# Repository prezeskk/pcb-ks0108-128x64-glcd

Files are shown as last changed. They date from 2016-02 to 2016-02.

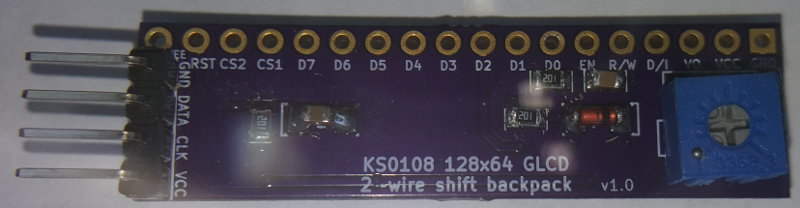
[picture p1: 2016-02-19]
doc/Soldered-Front.jpg

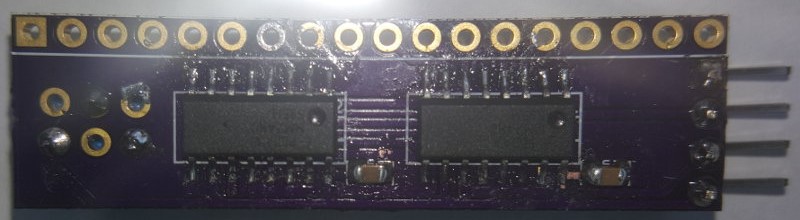
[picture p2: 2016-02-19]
doc/Soldered-Back.jpg

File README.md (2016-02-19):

# KS0108 128x64 Graphic LCD - 2-wire shift register backpack - v1.0 #

## Schematic ##



## Design Rules ##

* Clearance: 8 mil
* Track Width: 20 mil
* Via Diameter: 27 mil
* Via Drill: 13 mil
* Zone Clearance: 8 mil
* Zone Min Width: 8 mil
* Zone Thermal Antipad Clearance: 8 mil
* Zone Thermal Spoke Width: 15 mil

## PCB available on OSH Park ##

* 1.80" x 0.50" (45.82 mm x 12.80 mm)
* $1.50 each ($4.50 for 3)
* [https://oshpark.com/shared_projects/MtvXj55o](https://oshpark.com/shared_projects/MtvXj55o)

### PCB Front ###



### PCB Back ###



### Soldered Front ###



### Soldered Back ###



### Working Front ###



### Working Back ###



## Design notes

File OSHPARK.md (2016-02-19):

##KS0108 128x64 Graphic LCD - 2-wire shift register backpack - v1.0##

$1.50 each ($4.50 for 3)

NOTE: Working design, but AVR-GCC / Arduino library have not yet been published.

Component: [Sizes] **Values** (description)

* U1,U2: [SOIC-16N] **74HC595** (the shift registers)
* VR1: [3296W, 3362P (or similar)] **10k** (for contrast control)
* C1,C2: [0805] **0.1uF** (decoupling capacitors)
* C3: [1206] **1uF** (for reset delay)
* C4: [0805] **1nF** (for LCD enable line delay)
* D1: [SOD80 (~1206)] **LL4148** (for shift register latch)
* R1,R2,R3: [0805] **1k** (for shift register latch and LCD enable line delay)

[https://bitbucket.org/serisman/pcb-ks0108-128x64-glcd-backpack](https://bitbucket.org/serisman/pcb-ks0108-128x64-glcd-backpack)







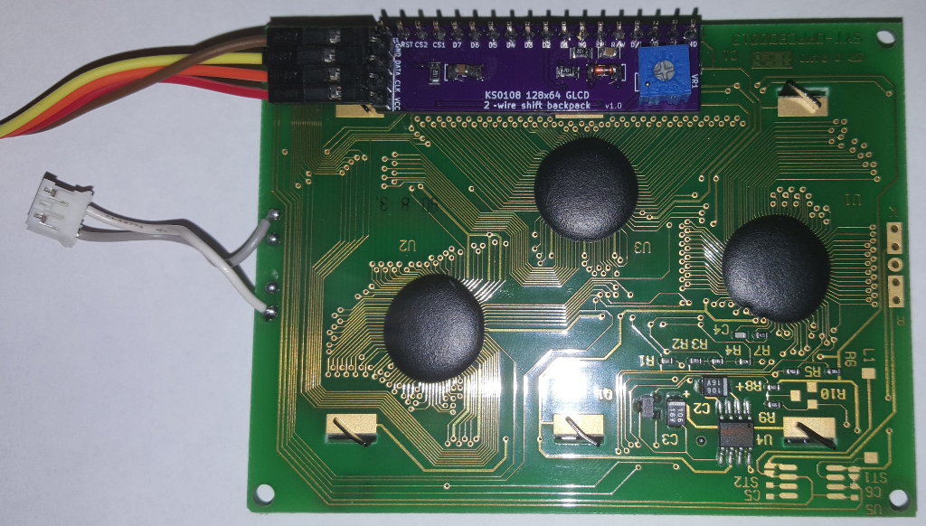
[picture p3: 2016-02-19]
doc/Working-Back.jpg

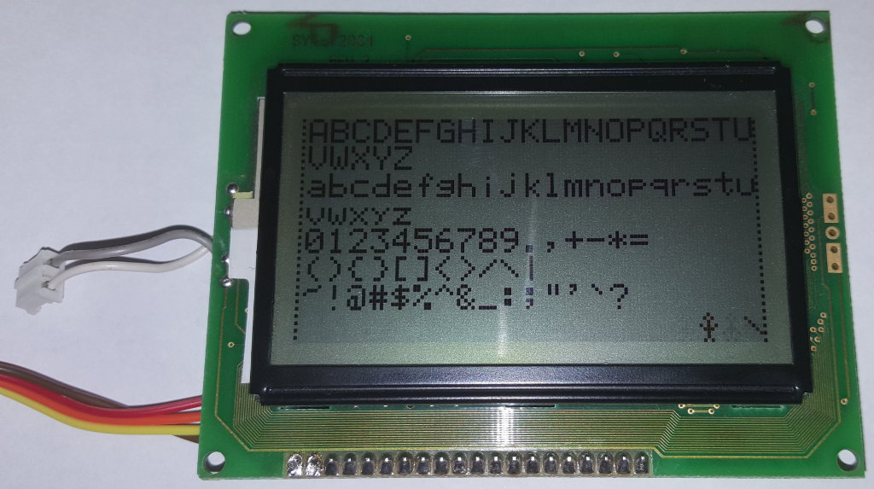
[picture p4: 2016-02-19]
doc/Working-Front.jpg

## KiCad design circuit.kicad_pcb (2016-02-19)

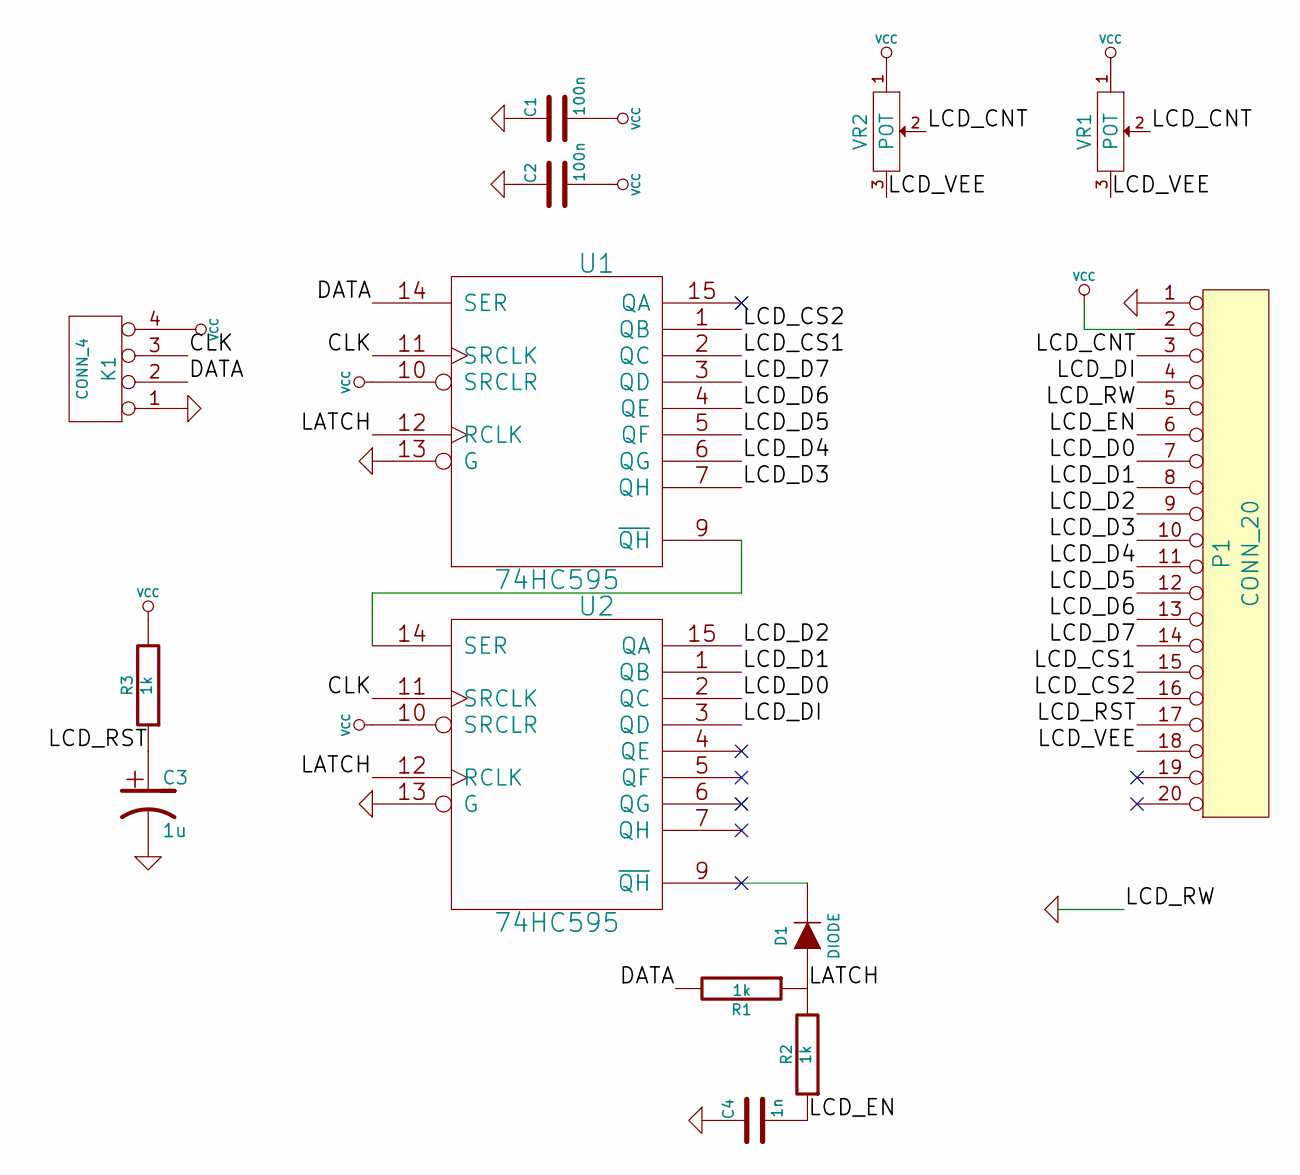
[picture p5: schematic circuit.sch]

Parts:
C1, C2: 100n
C3: 1u
C4: 1n
D1: DIODE
K1: CONN_4
P1: CONN_20
R1, R2, R3: 1k
U1, U2: 74HC595
VR1, VR2: POT

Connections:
/CLK: K1.3, U1.11 (SRCLK), U2.11 (SRCLK)
/DATA: K1.2, R1.2, U1.14 (SER)
/LATCH: D1.1 (A), R1.1, R2.2, U1.12 (RCLK), U2.12 (RCLK)
/LCD_CNT: P1.3, VR1.2, VR2.2
/LCD_CS1: P1.15, U1.2 (QC)
/LCD_CS2: P1.16, U1.1 (QB)
/LCD_D0: P1.7, U2.2 (QC)
/LCD_D1: P1.8, U2.1 (QB)
/LCD_D2: P1.9, U2.15 (QA)
/LCD_D3: P1.10, U1.7 (QH)
/LCD_D4: P1.11, U1.6 (QG)
/LCD_D5: P1.12, U1.5 (QF)
/LCD_D6: P1.13, U1.4 (QE)
/LCD_D7: P1.14, U1.3 (QD)
/LCD_DI: P1.4, U2.3 (QD)
/LCD_EN: C4.2, P1.6, R2.1
/LCD_RST: C3.1, P1.17, R3.1
/LCD_VEE: P1.18, VR1.3, VR2.3
GND: C1.1, C2.1, C3.2, C4.1, K1.1, P1.1, P1.5, U1.8 (GND), U1.13 (G), U2.8 (GND), U2.13 (G)
unnamed: U1.9 (~QH), U2.14 (SER)
unnamed: D1.2 (K), U2.9 (~QH)
VCC: C1.2, C2.2, K1.4, P1.2, R3.2, U1.10 (SRCLR), U1.16 (VCC), U2.10 (SRCLR), U2.16 (VCC), VR1.1, VR2.1

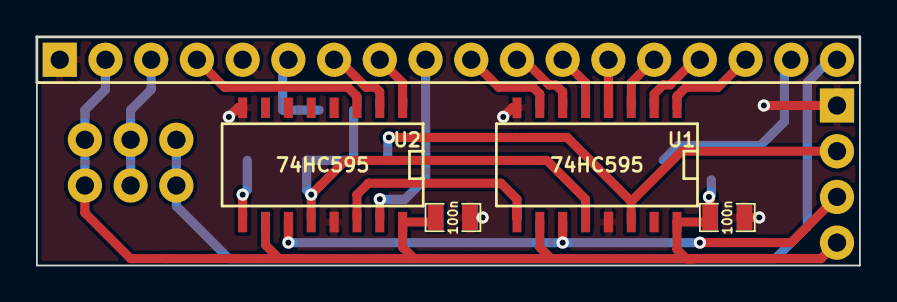
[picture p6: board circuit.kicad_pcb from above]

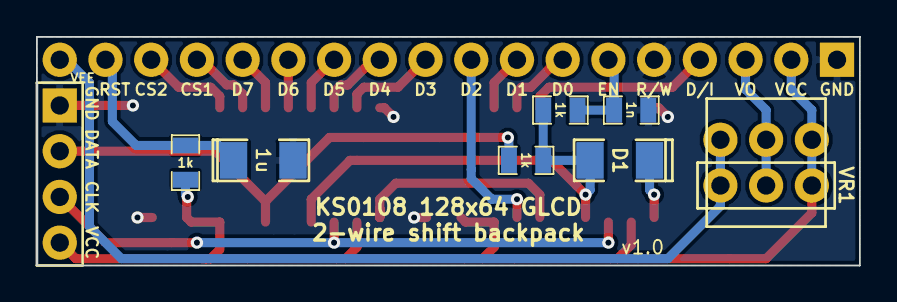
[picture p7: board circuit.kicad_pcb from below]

Board: 2 copper layers, 45.7 x 12.7 mm, 14 parts (9 on the bottom side), 22 nets.

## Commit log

2016-02-19 Initial Working Version (v1.0)
    [circuit-B_Cu.gbl, circuit-B_Mask.gbs, circuit-B_SilkS.gbo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]
2016-02-19 Fix gerber output directory
    [circuit.kicad_pcb]
2016-02-19 Add 'Soldered' and 'Working' pictures to README.md
2016-02-19 Swap PCB-Back <--> PCB-Front
2016-02-19 Rotate Soldered-Back.jpg
